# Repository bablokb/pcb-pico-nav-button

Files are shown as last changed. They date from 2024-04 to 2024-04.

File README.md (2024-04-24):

Slider and Navigation-Button PCB for the Raspberry Pi Pico
==========================================================

This is a little PCB for the Pico featuring a slider and a 5-way navigational button.

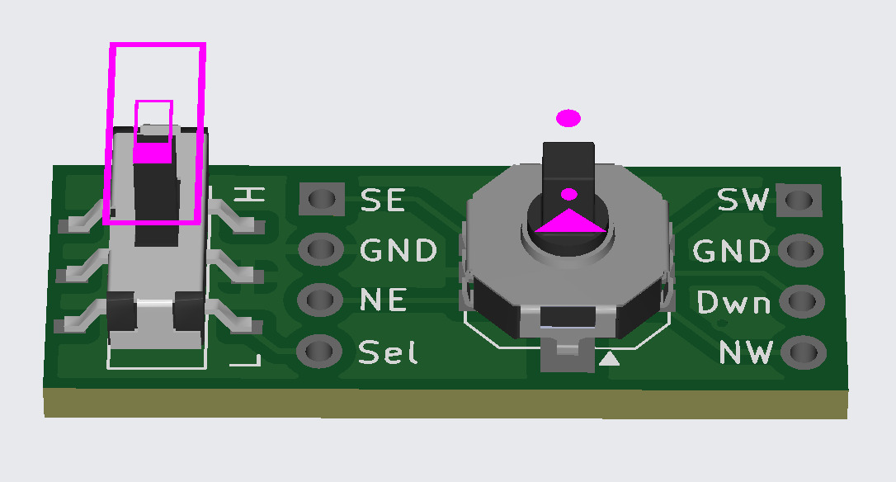
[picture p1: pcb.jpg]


The PCB uses 6 GPIOs: one for the slider, five for the navigational button:

    P1 (SE)        P2  (SW)
    GND            GND
    P3 (NE)        P4  (Down)
    P5 (Slider)    P6  (NW)

There are four options for mounting the PCB on the back of the Pico
(viewing from the back, the high GP-numbers are on the left):

  - GP28-GP26 / GP5-GP7
  - GP22-GP20 / GP12-GP15
  - GP19-GP17 / GP12-GP14 (rotated!)
  - GP18-GP16 / GP13-GP15

KiCAD (V6) files are available in the directory `pico-nav-button`. Ready to use
production files for JLCPCB are in the directory `production_files`.

Schematic and Layout
--------------------

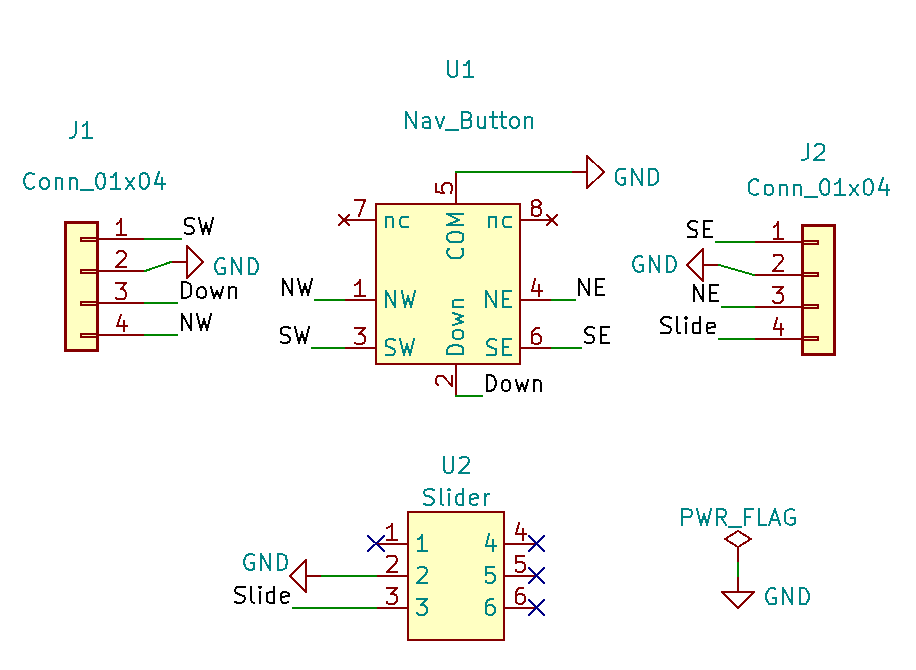
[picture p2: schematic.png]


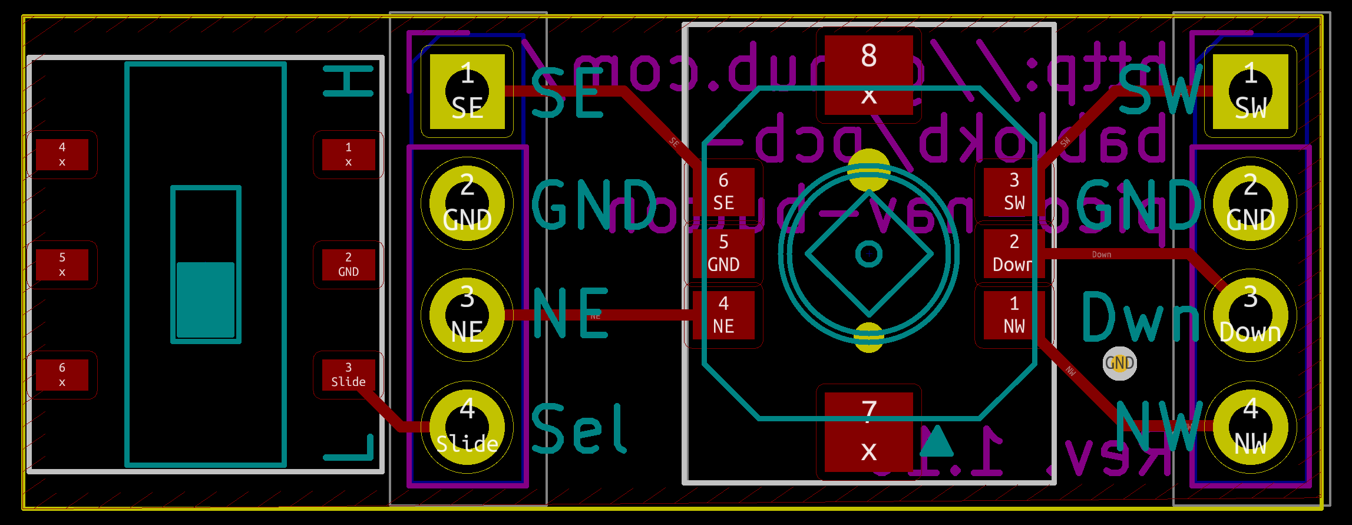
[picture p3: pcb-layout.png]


3D-View
-------

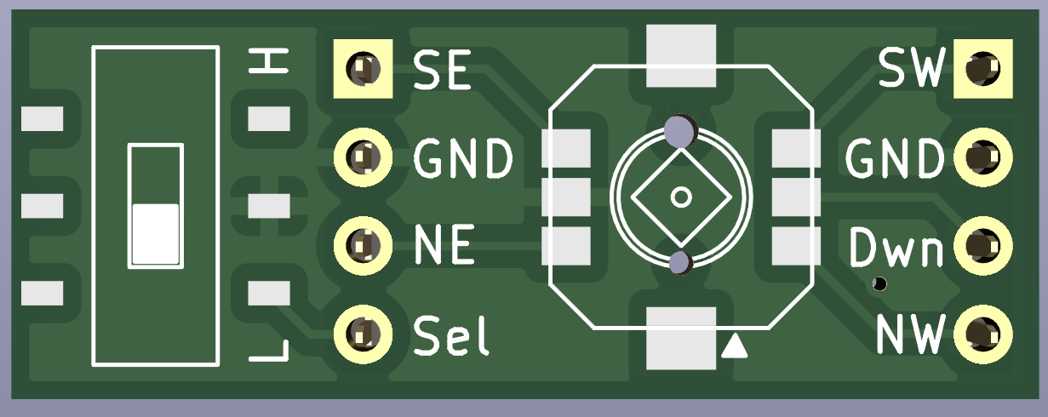
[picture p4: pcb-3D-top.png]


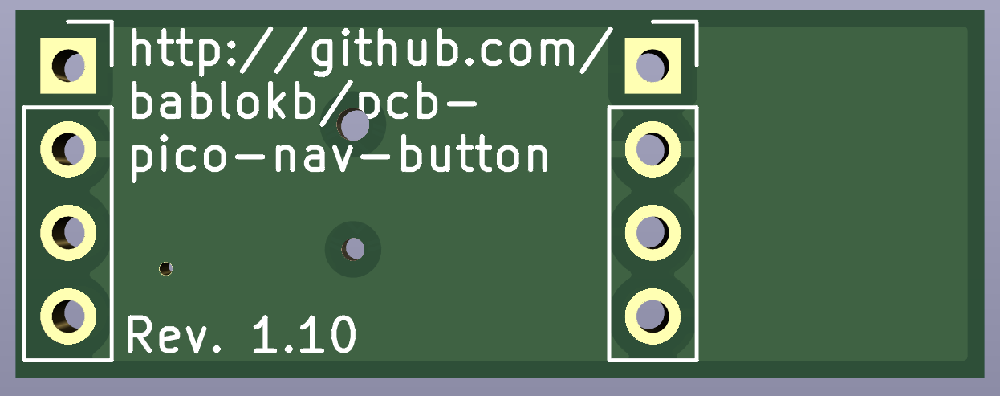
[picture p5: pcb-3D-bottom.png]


License
-------

[![CC BY-SA 4.0][cc-by-sa-shield]][cc-by-sa]

This work is licensed under a
[Creative Commons Attribution-ShareAlike 4.0 International
License][cc-by-sa].

[][cc-by-sa]

[cc-by-sa]: http://creativecommons.org/licenses/by-sa/4.0/
[cc-by-sa-image]: https://licensebuttons.net/l/by-sa/4.0/88x31.png
[cc-by-sa-shield]:
https://img.shields.io/badge/License-CC%20BY--SA%204.0-lightgrey.svg

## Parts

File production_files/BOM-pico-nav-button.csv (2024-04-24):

Comment | Designator | Footprint | LCSC
Nav_Button | U1 | Nav_Button_5x | C145898
Slider | U2 | Slider | C381098
Conn_01x04 | J1 | PinSocket_1x04_P2.54mm_Vertical
Conn_01x04 | J2 | PinSocket_1x04_P2.54mm_Vertical

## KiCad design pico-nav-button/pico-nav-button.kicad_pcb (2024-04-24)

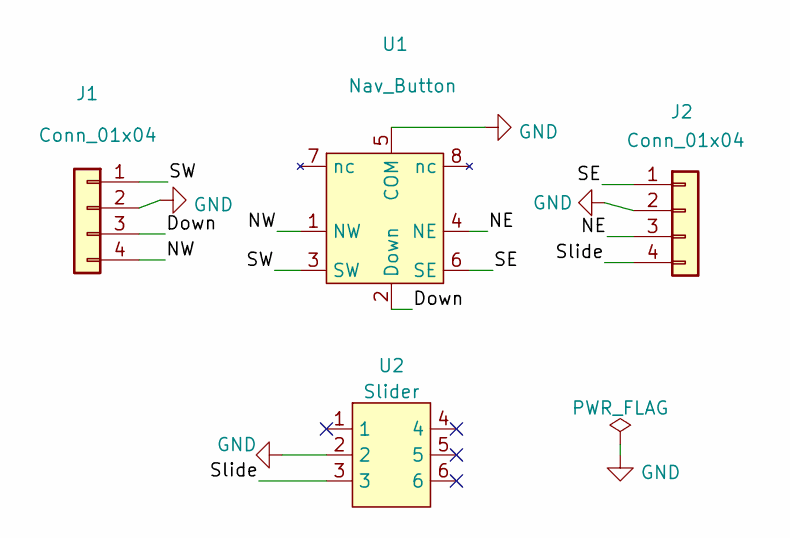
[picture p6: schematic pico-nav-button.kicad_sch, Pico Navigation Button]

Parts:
J1, J2: Conn_01x04; PinSocket_1x04_P2.54mm_Vertical
U1: Nav_Button; Nav_Button_5x; LCSC C145898
U2: Slider; LCSC C381098

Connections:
/Down: J1.3, U1.2 (Down)
/NE: J2.3, U1.4 (NE)
/NW: J1.4, U1.1 (NW)
/SE: J2.1, U1.6 (SE)
/SW: J1.1, U1.3 (SW)
/Slide: J2.4, U2.3
GND: J1.2, J2.2, U1.5 (COM), U2.2

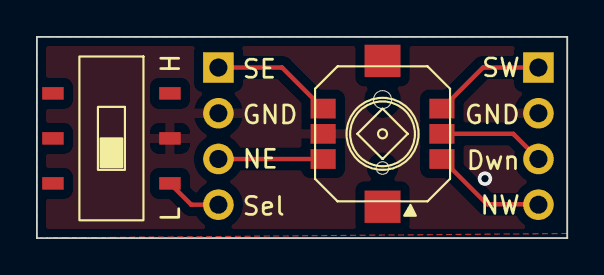
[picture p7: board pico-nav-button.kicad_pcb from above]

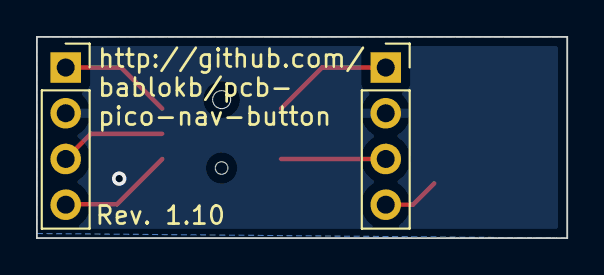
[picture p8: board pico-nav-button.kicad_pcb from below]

Board: 2 copper layers, 29.5 x 11.2 mm, 4 parts (2 on the bottom side), 7 nets.

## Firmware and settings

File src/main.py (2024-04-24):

# ----------------------------------------------------------------------------
# Example program for nav-button + slider.
#
# Author: Bernhard Bablok
# License: GPL3
#
# Website: https://github.com/bablokb/pcb-pico-nav-button
#
# ----------------------------------------------------------------------------

# Note: revision 1.0 has a wrong pin-to-pad mapping and therefore does
#       not support "push"
REVISION = "1.0"

import board
import time
import keypad
import digitalio

# --- pin configuration   ---------------------------------------------------

PIN_SLIDER = board.GP16
if REVISION == "1.0":
  PIN_SE     = board.GP17
  PIN_NE     = board.GP18
  PIN_SW     = board.GP15
  PIN_COMMON = board.GP14
  PIN_NW     = board.GP13
else:
  PIN_SE     = board.GP18
  PIN_NE     = board.GP16
  PIN_SW     = board.GP13
  PIN_DOWN   = board.GP14
  PIN_NW     = board.GP15

# --- objects   -------------------------------------------------------------

if REVISION == "1.0":
  # common plays role of GND
  common = digitalio.DigitalInOut(PIN_COMMON)
  common.direction = digitalio.Direction.OUTPUT
  common.value = False
  keys  = [PIN_SE,PIN_NE,PIN_SW,PIN_NW]
  names = ["SE","NE","SW","NW"]
else:
  keys  = [PIN_SE,PIN_NE,PIN_SW,PIN_NW,PIN_DOWN]
  names = ["SE","NE","SW","NW","DOWN"]

nav = keypad.Keys(keys,
                  value_when_pressed=False,pull=True,
                  interval=0.1,max_events=4)

slider = digitalio.DigitalInOut(PIN_SLIDER)
slider.direction = digitalio.Direction.INPUT
slider.pull      = digitalio.Pull.UP

# --- query keys and slider   -----------------------------------------------

slider_old = slider.value
print(f"current slider setting: {slider_old}")

while True:
  slider_new = slider.value
  if slider_new != slider_old:
    print(f"slider changed from {slider_old} to {slider_new}")
    slider_old = slider_new

  event = nav.events.get()
  if event and event.pressed:
    print(f"navigation with key: {names[event.key_number]}")

  time.sleep(0.1)

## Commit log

2024-04-24 Rev 1.00: initial commit
    [BOM-pico-nav-button.csv, pico-nav-button.kicad_pcb, pico-nav-button.kicad_sch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]
2024-04-24 Rev 1.10: fixed pad-to-pin assignments
    [pico-nav-button.kicad_pcb, pico-nav-button.kicad_sch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]
2024-04-24 added example program (CircuitPython)
